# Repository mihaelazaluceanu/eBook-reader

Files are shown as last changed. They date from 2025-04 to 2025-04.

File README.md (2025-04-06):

# eBook Reader - Zaluceanu Mihaela
Dispozitiv electronic, portabil,  folosit drept cititor de e-books, construit în jurul modulului **ESP32-C6-WROOM-1-N8**.

### Diagrama Bloc
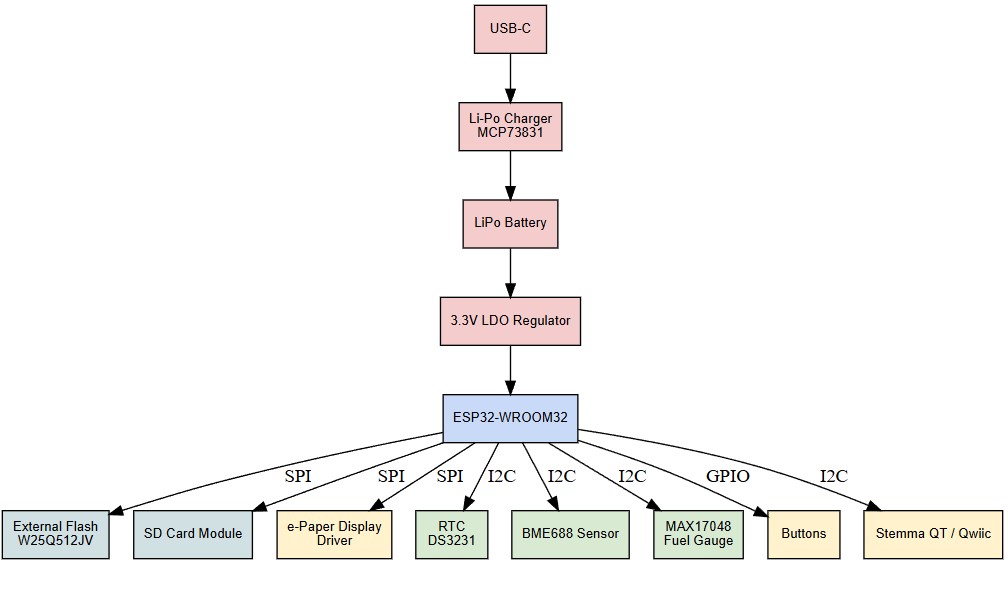
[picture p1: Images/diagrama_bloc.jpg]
Diagrama Bloc


### BOM (Bill of Materials)
**Note:** TP-urile nu apar în tabel deoarece pentru implementarea acestora am folost un design propriu.

  | Nr. | Component Name | Procurement Link | Datasheet Link |
  |-----|----------------|------------------|----------------|
  | 1 | BOOT_BUTON | [Link](https://www.snapeda.com/parts/EVQP7L01P/Panasonic%20Electronic%20Components/view-part/?welcome=home) | [Datasheet](https://www.snapeda.com/parts/EVQP7L01P/Panasonic/datasheet/) |
  | 2 | C1 | [Link](https://componentsearchengine.com/part-view/CC0402MRX5R5BB106/YAGEO) | [Datasheet](https://componentsearchengine.com/Datasheets/2/CC0402MRX5R5BB106.pdf) |
  | 3 | C1_BAT | [Link](https://componentsearchengine.com/part-view/CC0402MRX5R5BB106/YAGEO) | [Datasheet](https://componentsearchengine.com/Datasheets/2/CC0402MRX5R5BB106.pdf) |
  | 4 | C1_BAT2 | [Link](https://componentsearchengine.com/part-view/CC0402MRX5R5BB106/YAGEO) | [Datasheet](https://componentsearchengine.com/Datasheets/2/CC0402MRX5R5BB106.pdf) |
  | 5 | C2 | [Link](https://componentsearchengine.com/part-view/CC0402MRX5R5BB106/YAGEO) | [Datasheet](https://componentsearchengine.com/Datasheets/2/CC0402MRX5R5BB106.pdf) |
  | 6 | C2_BAT | [Link](https://componentsearchengine.com/part-view/CC0402MRX5R5BB106/YAGEO) | [Datasheet](https://componentsearchengine.com/Datasheets/2/CC0402MRX5R5BB106.pdf) |
  | 7 | C3 | [Link](https://componentsearchengine.com/part-view/CC0402MRX5R5BB106/YAGEO) | [Datasheet](https://componentsearchengine.com/Datasheets/2/CC0402MRX5R5BB106.pdf) |
  | 8 | C4 | [Link](https://componentsearchengine.com/part-view/CC0402MRX5R5BB106/YAGEO) | [Datasheet](https://componentsearchengine.com/Datasheets/2/CC0402MRX5R5BB106.pdf) |
  | 9 | C4_USB | [Link](https://componentsearchengine.com/part-view/CC0402MRX5R5BB106/YAGEO) | [Datasheet](https://componentsearchengine.com/Datasheets/2/CC0402MRX5R5BB106.pdf) |
  | 10 | C5 | [Link](https://componentsearchengine.com/part-view/CC0402MRX5R5BB106/YAGEO) | [Datasheet](https://componentsearchengine.com/Datasheets/2/CC0402MRX5R5BB106.pdf) |
  | 11 | C5_USB | [Link](https://componentsearchengine.com/part-view/CC0402MRX5R5BB106/YAGEO) | [Datasheet](https://componentsearchengine.com/Datasheets/2/CC0402MRX5R5BB106.pdf) |
  | 12 | C6 | [Link](https://componentsearchengine.com/part-view/CC0402MRX5R5BB106/YAGEO) | [Datasheet](https://componentsearchengine.com/Datasheets/2/CC0402MRX5R5BB106.pdf) |
  | 13 | C7 | [Link](https://componentsearchengine.com/part-view/CC0402MRX5R5BB106/YAGEO) | [Datasheet](https://componentsearchengine.com/Datasheets/2/CC0402MRX5R5BB106.pdf) |
  | 14 | C8 | [Link](https://componentsearchengine.com/part-view/CC0402MRX5R5BB106/YAGEO) | [Datasheet](https://componentsearchengine.com/Datasheets/2/CC0402MRX5R5BB106.pdf) |
  | 15 | C9 | [Link](https://componentsearchengine.com/part-view/CC0402MRX5R5BB106/YAGEO) | [Datasheet](https://componentsearchengine.com/Datasheets/2/CC0402MRX5R5BB106.pdf) |
  | 16 | C10 | [Link](https://componentsearchengine.com/part-view/CC0402MRX5R5BB106/YAGEO) | [Datasheet](https://componentsearchengine.com/Datasheets/2/CC0402MRX5R5BB106.pdf) |
  | 17 | C10_SUPERCAR | [Link](https://industry.panasonic.com/global/en/products/control/switch/light-touch/number/evqpuj02k) | [Datasheet](https://industry.panasonic.com/global/en/downloads?tab=catalog&small_g_cd=203&part_no=EVQPUJ02K) |
  | 18 | CHANGE_BUTTON | [Link](https://www.snapeda.com/parts/EVQP7L01P/Panasonic%20Electronic%20Components/view-part/?welcome=home) | [Datasheet](https://www.snapeda.com/parts/EVQP7L01P/Panasonic/datasheet/) |
  | 19 | C_DELAY | [Link](https://componentsearchengine.com/part-view/CC0402MRX5R5BB106/YAGEO) | [Datasheet](https://componentsearchengine.com/Datasheets/2/CC0402MRX5R5BB106.pdf) |
  | 20 | D1 | [Link](https://www.snapeda.com/parts/USBLC6-2SC6Y/STMicroelectronics/view-part/?ref=eda) | [Datasheet](https://www.snapeda.com/parts/USBLC6-2SC6Y/STMicroelectronics/view-part/?ref=eda) |
  | 21 | D2 | [Link](https://ro.mouser.com/ProductDetail/KYOCERA-AVX/SD0805S020S1R0?qs=jCA%252BPfw4LHbpkAoSnwrdjw%3D%3D) | [Datasheet](https://ro.mouser.com/datasheet/2/40/schottky-3165252.pdf) |
  | 22 | D3 | [Link](https://ro.mouser.com/ProductDetail/KYOCERA-AVX/SD0805S020S1R0?qs=jCA%252BPfw4LHbpkAoSnwrdjw%3D%3D) | [Datasheet](https://ro.mouser.com/datasheet/2/40/schottky-3165252.pdf) |
  | 23 | D4 | [Link](https://ro.mouser.com/ProductDetail/KYOCERA-AVX/SD0805S020S1R0?qs=jCA%252BPfw4LHbpkAoSnwrdjw%3D%3D) | [Datasheet](https://ro.mouser.com/datasheet/2/40/schottky-3165252.pdf) |
  | 24 | D5 | [Link](https://ro.mouser.com/ProductDetail/KYOCERA-AVX/SD0805S020S1R0?qs=jCA%252BPfw4LHbpkAoSnwrdjw%3D%3D) | [Datasheet](https://ro.mouser.com/datasheet/2/40/schottky-3165252.pdf) |
  | 25 | D6 | [Link](https://www.snapeda.com/parts/PGB1010603MR/Littelfuse/view-part/?ref=eda) | [Datasheet](https://www.snapeda.com/parts/PGB1010603MR/Littelfuse%20Inc./datasheet/) |
  | 26 | D7 | [Link](https://ro.mouser.com/ProductDetail/KYOCERA-AVX/SD0805S020S1R0?qs=jCA%252BPfw4LHbpkAoSnwrdjw%3D%3D) | [Datasheet](https://ro.mouser.com/datasheet/2/40/schottky-3165252.pdf) |
  | 27 | D8 | [Link](https://www.snapeda.com/parts/PGB1010603MR/Littelfuse/view-part/?ref=eda) | [Datasheet](https://www.snapeda.com/parts/PGB1010603MR/Littelfuse%20Inc./datasheet/) |
  | 28 | D9 | [Link](https://www.snapeda.com/parts/PGB1010603MR/Littelfuse/view-part/?ref=eda) | [Datasheet](https://www.snapeda.com/parts/PGB1010603MR/Littelfuse%20Inc./datasheet/) |
  | 29 | D10 | [Link](https://www.snapeda.com/parts/PGB1010603MR/Littelfuse/view-part/?ref=eda) | [Datasheet](https://www.snapeda.com/parts/PGB1010603MR/Littelfuse%20Inc./datasheet/) |
  | 30 | D11 | [Link](https://www.snapeda.com/parts/PGB1010603MR/Littelfuse/view-part/?ref=eda) | [Datasheet](https://www.snapeda.com/parts/PGB1010603MR/Littelfuse%20Inc./datasheet/) |
  | 31 | D12 | [Link](https://www.snapeda.com/parts/PGB1010603MR/Littelfuse/view-part/?ref=eda) | [Datasheet](https://www.snapeda.com/parts/PGB1010603MR/Littelfuse%20Inc./datasheet/) |
  | 32 | EPD_C1 | [Link](https://componentsearchengine.com/part-view/CC0402MRX5R5BB106/YAGEO) | [Datasheet](https://componentsearchengine.com/Datasheets/2/CC0402MRX5R5BB106.pdf) |
  | 33 | EPD_C2 | [Link](https://componentsearchengine.com/part-view/CC0402MRX5R5BB106/YAGEO) | [Datasheet](https://componentsearchengine.com/Datasheets/2/CC0402MRX5R5BB106.pdf) |
  | 34 | EPD_C5 | [Link](https://componentsearchengine.com/part-view/CC0402MRX5R5BB106/YAGEO) | [Datasheet](https://componentsearchengine.com/Datasheets/2/CC0402MRX5R5BB106.pdf) |
  | 35 | EPD_C6 | [Link](https://componentsearchengine.com/part-view/CC0402MRX5R5BB106/YAGEO) | [Datasheet](https://componentsearchengine.com/Datasheets/2/CC0402MRX5R5BB106.pdf) |
  | 36 | EPD_C7 | [Link](https://componentsearchengine.com/part-view/CC0402MRX5R5BB106/YAGEO) | [Datasheet](https://componentsearchengine.com/Datasheets/2/CC0402MRX5R5BB106.pdf) |
  | 37 | EPD_C8 | [Link](https://componentsearchengine.com/part-view/CC0402MRX5R5BB106/YAGEO) | [Datasheet](https://componentsearchengine.com/Datasheets/2/CC0402MRX5R5BB106.pdf) |
  | 38 | EPD_C9 | [Link](https://componentsearchengine.com/part-view/CC0402MRX5R5BB106/YAGEO) | [Datasheet](https://componentsearchengine.com/Datasheets/2/CC0402MRX5R5BB106.pdf) |
  | 39 | EPD_C10 | [Link](https://componentsearchengine.com/part-view/CC0402MRX5R5BB106/YAGEO) | [Datasheet](https://componentsearchengine.com/Datasheets/2/CC0402MRX5R5BB106.pdf) |
  | 40 | EPD_C11 | [Link](https://componentsearchengine.com/part-view/CC0402MRX5R5BB106/YAGEO) | [Datasheet](https://componentsearchengine.com/Datasheets/2/CC0402MRX5R5BB106.pdf) |
  | 41 | EPD_C12 | [Link](https://componentsearchengine.com/part-view/CC0402MRX5R5BB106/YAGEO) | [Datasheet](https://componentsearchengine.com/Datasheets/2/CC0402MRX5R5BB106.pdf) |
  | 42 | IC1 | [Link](https://componentsearchengine.com/part-view/BD5229G-TR/ROHM%20Semiconductor) | [Datasheet](https://datasheet.datasheetarchive.com/originals/distributors/Datasheets_SAMA/f2b9741ef86007909f138d561a359946.pdf) |
  | 43 | IC4 | [Link](https://componentsearchengine.com/part-view/XC6220A331MR-G/Torex) | [Datasheet](https://product.torexsemi.com/system/files/series/xc6220.pdf) |
  | 44 | J1 | [Link](https://componentsearchengine.com/part-view/FH34SRJ-24S-0.5SH(99)/Hirose) | [Datasheet](https://www.hirose.com/en/product/document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) |
  | 45 | J2 | [Link](https://componentsearchengine.com/part-view/USB4110-GF-A/GCT%20(GLOBAL%20CONNECTOR%20TECHNOLOGY)) | [Datasheet](https://gct.co/files/drawings/usb4110.pdf) |
  | 46 | J3 | [Link](https://www.snapeda.com/parts/PRT-14417/SparkFun/view-part/) | [Datasheet](https://www.snapeda.com/parts/PRT-14417/SparkFun%20Electronics/datasheet/) |
  | 47 | J4 | [Link](https://www.snapeda.com/parts/112A-TAAR-R03/Attend/view-part/) | [Datasheet](https://www.snapeda.com/parts/112A-TAAR-R03/Attend/datasheet/) |
  | 48 | MCP73831 | [Link](https://ro.mouser.com/ProductDetail/Microchip-Technology/MCP73831T-2ACI-OT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) | [Datasheet](https://ro.mouser.com/datasheet/2/268/MCP73831_Family_Data_Sheet_DS20001984H-3441711.pdf) |
  | 49 | L1 | [Link](https://ro.mouser.com/ProductDetail/Wurth-Elektronik/744043680?qs=PGXP4M47uW6VkZq%252BkzjrHA%3D%3D) | [Datasheet](https://www.we-online.com/components/products/datasheet/744043680.pdf) |
  | 50 | PFMF.050.1 | [Link](https://ro.mouser.com/ProductDetail/EPCOS-TDK/B72520T0350K062?qs=dEfas%2FXlABIszF52uu7vrg%3D%3D) | [Datasheet](https://www.tdk-electronics.tdk.com/inf/75/db/CTVS_14/Surge_protection_series.pdf) |
  | 51 | Q1 | [Link](https://componentsearchengine.com/part-view/DMG2305UX-7/Diodes%20Incorporated) | [Datasheet](https://www.diodes.com//assets/Datasheets/DMG2305UX.pdf) |
  | 52 | Q2 | [Link](https://componentsearchengine.com/part-view/DMG2305UX-7/Diodes%20Incorporated) | [Datasheet](https://www.diodes.com//assets/Datasheets/DMG2305UX.pdf) |
  | 53 | Q3 | [Link](https://componentsearchengine.com/part-view/SI1308EDL-T1-GE3/Vishay) | [Datasheet](https://componentsearchengine.com/part-view/SI1308EDL-T1-GE3/Vishay) |
  | 54 | R1 | [Link](https://componentsearchengine.com/part-view/R0402%201%25%20100%20K%20(RC0402FR-07100KL)/YAGEO) | [Datasheet](https://www.yageo.com/upload/media/product/products/datasheet/rchip/PYu-RC_Group_51_RoHS_L_12.pdf) |
  | 55 | R1_PINH | [Link](https://componentsearchengine.com/part-view/R0402%201%25%20100%20K%20(RC0402FR-07100KL)/YAGEO) | [Datasheet](https://www.yageo.com/upload/media/product/products/datasheet/rchip/PYu-RC_Group_51_RoHS_L_12.pdf) |
  | 56 | R1_PINH1 | [Link](https://componentsearchengine.com/part-view/R0402%201%25%20100%20K%20(RC0402FR-07100KL)/YAGEO) | [Datasheet](https://www.yageo.com/upload/media/product/products/datasheet/rchip/PYu-RC_Group_51_RoHS_L_12.pdf) |
  | 57 | R1_BAT | [Link](https://componentsearchengine.com/part-view/R0402%201%25%20100%20K%20(RC0402FR-07100KL)/YAGEO) | [Datasheet](https://www.yageo.com/upload/media/product/products/datasheet/rchip/PYu-RC_Group_51_RoHS_L_12.pdf) |
  | 58 | R1_PWRUSB | [Link](https://componentsearchengine.com/part-view/R0402%201%25%20100%20K%20(RC0402FR-07100KL)/YAGEO) | [Datasheet](https://www.yageo.com/upload/media/product/products/datasheet/rchip/PYu-RC_Group_51_RoHS_L_12.pdf) |
  | 59 | R2 | [Link](https://componentsearchengine.com/part-view/R0402%201%25%20100%20K%20(RC0402FR-07100KL)/YAGEO) | [Datasheet](https://www.yageo.com/upload/media/product/products/datasheet/rchip/PYu-RC_Group_51_RoHS_L_12.pdf) |
  | 60 | R2_PINH | [Link](https://componentsearchengine.com/part-view/R0402%201%25%20100%20K%20(RC0402FR-07100KL)/YAGEO) | [Datasheet](https://www.yageo.com/upload/media/product/products/datasheet/rchip/PYu-RC_Group_51_RoHS_L_12.pdf) |
  | 61 | R2-PINH1 | [Link](https://componentsearchengine.com/part-view/R0402%201%25%20100%20K%20(RC0402FR-07100KL)/YAGEO) | [Datasheet](https://www.yageo.com/upload/media/product/products/datasheet/rchip/PYu-RC_Group_51_RoHS_L_12.pdf) |
  | 62 | R2 | [Link](https://componentsearchengine.com/part-view/R0402%201%25%20100%20K%20(RC0402FR-07100KL)/YAGEO) | [Datasheet](https://www.yageo.com/upload/media/product/products/datasheet/rchip/PYu-RC_Group_51_RoHS_L_12.pdf) |
  | 63 | R2-PINH | [Link](https://componentsearchengine.com/part-view/R0402%201%25%20100%20K%20(RC0402FR-07100KL)/YAGEO) | [Datasheet](https://www.yageo.com/upload/media/product/products/datasheet/rchip/PYu-RC_Group_51_RoHS_L_12.pdf) |
  | 64 | R2-PINH1 | [Link](https://componentsearchengine.com/part-view/R0402%201%25%20100%20K%20(RC0402FR-07100KL)/YAGEO) | [Datasheet](https://www.yageo.com/upload/media/product/products/datasheet/rchip/PYu-RC_Group_51_RoHS_L_12.pdf) |
  | 65 | R2_USB | [Link](https://componentsearchengine.com/part-view/R0402%201%25%20100%20K%20(RC0402FR-07100KL)/YAGEO) | [Datasheet](https://www.yageo.com/upload/media/product/products/datasheet/rchip/PYu-RC_Group_51_RoHS_L_12.pdf) |
  | 66 | R2_USB | [Link](https://componentsearchengine.com/part-view/R0402%201%25%20100%20K%20(RC0402FR-07100KL)/YAGEO) | [Datasheet](https://www.yageo.com/upload/media/product/products/datasheet/rchip/PYu-RC_Group_51_RoHS_L_12.pdf) |
  | 67 | R2_USB1 | [Link](https://componentsearchengine.com/part-view/R0402%201%25%20100%20K%20(RC0402FR-07100KL)/YAGEO) | [Datasheet](https://www.yageo.com/upload/media/product/products/datasheet/rchip/PYu-RC_Group_51_RoHS_L_12.pdf) |
  | 68 | R3 | [Link](https://componentsearchengine.com/part-view/R0402%201%25%20100%20K%20(RC0402FR-07100KL)/YAGEO) | [Datasheet](https://www.yageo.com/upload/media/product/products/datasheet/rchip/PYu-RC_Group_51_RoHS_L_12.pdf) |
  | 69 | R4 | [Link](https://componentsearchengine.com/part-view/R0402%201%25%20100%20K%20(RC0402FR-07100KL)/YAGEO) | [Datasheet](https://www.yageo.com/upload/media/product/products/datasheet/rchip/PYu-RC_Group_51_RoHS_L_12.pdf) |
  | 70 | R5 | [Link](https://componentsearchengine.com/part-view/R0402%201%25%20100%20K%20(RC0402FR-07100KL)/YAGEO) | [Datasheet](https://www.yageo.com/upload/media/product/products/datasheet/rchip/PYu-RC_Group_51_RoHS_L_12.pdf) |
  | 71 | R6 | [Link](https://componentsearchengine.com/part-view/R0402%201%25%20100%20K%20(RC0402FR-07100KL)/YAGEO) | [Datasheet](https://www.yageo.com/upload/media/product/products/datasheet/rchip/PYu-RC_Group_51_RoHS_L_12.pdf) |
  | 72 | R7 | [Link](https://componentsearchengine.com/part-view/R0402%201%25%20100%20K%20(RC0402FR-07100KL)/YAGEO) | [Datasheet](https://www.yageo.com/upload/media/product/products/datasheet/rchip/PYu-RC_Group_51_RoHS_L_12.pdf) |
  | 73 | R8 | [Link](https://componentsearchengine.com/part-view/R0402%201%25%20100%20K%20(RC0402FR-07100KL)/YAGEO) | [Datasheet](https://www.yageo.com/upload/media/product/products/datasheet/rchip/PYu-RC_Group_51_RoHS_L_12.pdf) |
  | 74 | R9 | [Link](https://componentsearchengine.com/part-view/R0402%201%25%20100%20K%20(RC0402FR-07100KL)/YAGEO) | [Datasheet](https://www.yageo.com/upload/media/product/products/datasheet/rchip/PYu-RC_Group_51_RoHS_L_12.pdf) |
  | 75 | R10 | [Link](https://componentsearchengine.com/part-view/R0402%201%25%20100%20K%20(RC0402FR-07100KL)/YAGEO) | [Datasheet](https://www.yageo.com/upload/media/product/products/datasheet/rchip/PYu-RC_Group_51_RoHS_L_12.pdf) |
  | 76 | RESET_BUTTON | [Link](https://www.snapeda.com/parts/EVQP7L01P/Panasonic%20Electronic%20Components/view-part/?welcome=home) | [Datasheet](https://www.snapeda.com/parts/EVQP7L01P/Panasonic/datasheet/) |
  | 77 | R_BOOT | [Link](https://componentsearchengine.com/part-view/R0402%201%25%20100%20K%20(RC0402FR-07100KL)/YAGEO) | [Datasheet](https://www.yageo.com/upload/media/product/products/datasheet/rchip/PYu-RC_Group_51_RoHS_L_12.pdf) |
  | 78 | R_CAPACITOR | [Link](https://componentsearchengine.com/part-view/R0402%201%25%20100%20K%20(RC0402FR-07100KL)/YAGEO) | [Datasheet](https://www.yageo.com/upload/media/product/products/datasheet/rchip/PYu-RC_Group_51_RoHS_L_12.pdf) |
  | 79 | R_CHANGE | [Link](https://componentsearchengine.com/part-view/R0402%201%25%20100%20K%20(RC0402FR-07100KL)/YAGEO) | [Datasheet](https://www.yageo.com/upload/media/product/products/datasheet/rchip/PYu-RC_Group_51_RoHS_L_12.pdf) |
  | 80 | R_CL1 | [Link](https://componentsearchengine.com/part-view/R0402%201%25%20100%20K%20(RC0402FR-07100KL)/YAGEO) | [Datasheet](https://www.yageo.com/upload/media/product/products/datasheet/rchip/PYu-RC_Group_51_RoHS_L_12.pdf) |
  | 81 | R_RESET | [Link](https://componentsearchengine.com/part-view/R0402%201%25%20100%20K%20(RC0402FR-07100KL)/YAGEO) | [Datasheet](https://www.yageo.com/upload/media/product/products/datasheet/rchip/PYu-RC_Group_51_RoHS_L_12.pdf) |
  | 82 | SENSOR2 | [Link](https://www.snapeda.com/parts/BME680/Bosch/view-part/?welcome=home) | [Datasheet](https://www.snapeda.com/parts/BME680/Bosch%20Sensortec/datasheet/) |
  | 83 | SJ1 | [Link](https://grabcad.com/library/solder-jumpers-1) | [Datasheet](https://grabcad.com/library/solder-jumpers-1) |
  | 84 | U1 | [Link](https://www.snapeda.com/parts/W25Q512JVEIQ/Winbond+Electronics/view-part/?ref=eda) | [Datasheet](https://www.snapeda.com/parts/W25Q512JVEIQ/Winbond+Electronics/view-part/?ref=eda) |
  | 85 | U2 | [Link](https://www.snapeda.com/parts/ESP32-C6-WROOM-1-N8/Espressif+Systems/view-part/?ref=eda) | [Datasheet](https://www.snapeda.com/parts/ESP32-C6-WROOM-1-N8/Espressif%20Systems/datasheet/) |
  | 86 | U3 | [Link](https://www.snapeda.com/parts/DS3231SN%23/Analog+Devices/view-part/?ref=eda) | [Datasheet](https://www.snapeda.com/parts/DS3231SN%23/Analog%20Devices/datasheet/) |
  | 87 | U4 | [Link](https://www.snapeda.com/parts/MAX17048G+T10/Analog+Devices/view-part/?ref=eda) | [Datasheet](https://www.snapeda.com/parts/MAX17048G+T10/Analog%20Devices/datasheet/) |

### Componente principale ale sistemului:

- **ESP32-C6-WROOM-1-N8** – Microcontroler principal cu conectivitate Wi-Fi și Bluetooth Low Energy (BLE) integrată. Responsabil pentru gestionarea comunicațiilor, a senzorilor și a afișajului.
- **BME688** – Senzor de mediu capabil să măsoare temperatura, umiditatea, presiunea atmosferică și compuși volatili (calitatea aerului). Comunică cu ESP32 prin interfața **I2C**.
- **DS3231SN** – Modul RTC (ceas în timp real) de înaltă precizie, conectat la ESP32 tot prin magistrala **I2C**, asigură păstrarea timpului chiar și în lipsa alimentării.
- **MAX17048** – Circuit de monitorizare a nivelului bateriei cu interfață **I2C**; oferă informații despre starea de încărcare (SOC - State of Charge).
- **Modul card SD** – Utilizat pentru stocarea locală a datelor colectate. Comunică prin interfața **SPI**.
- **Display E-Ink** – Afișaj monocrom cu consum foarte redus de energie, controlat prin **SPI**. Semnale de control: `EPD_CS`, `EPD_DC`, `EPD_RST`, `EPD_BUSY`;
- **Memorie NOR Flash (W25Q512JVEIQ, 64MB)** – Memorie externă conectată prin **SPI**, destinată stocării de firmware sau volume mari de date;
- **Butoane BOOT și RESET** – Conectate la pini GPIO ai ESP32, permit intrarea în modul bootloader și resetarea sistemului;
- **MCP73831** – Controler de încărcare pentru acumulatori Li-Po, conectat direct la baterie pentru gestionarea încărcării în siguranță;
- **LDO (Low Dropout Regulator) XC6220A331MR-G** – Regulator de tensiune de 3.3V, furnizează alimentarea stabilă pentru componentele logice;
- **Port USB-C (USB4110-GF-A)** – Asigură alimentarea dispozitivului, precum și comunicația serială pentru programare și depanare.

### ESP32-C6 Pin Mapping

| Pin ESP32-C6 | Componentă Legată | Funcție |
|---|---|---|
| GPIO0 | Flash Memory (DI) | SPI MOSI |
| GPIO1 | Flash Memory (DO) | SPI MISO |
| GPIO2 | Flash CS | Chip Select |
| GPIO3 | Flash HOLD | Hold/Reset |
| GPIO6 | E-Ink Display (EPD_DC)  | Data/Command Select  |
| GPIO7 | E-Ink Display (EPD_CS)  | Chip Select |
| GPIO8 | E-Ink Display (EPD_RST) | Reset |
| GPIO9 | E-Ink Display (BUSY) | Status Feedback |
| GPIO10 | SD Card (CS) | Chip Select |
| GPIO11 | SD Card (MOSI) | Data In |
| GPIO12 | SD Card (MISO) | Data Out |
| GPIO13 | SD Card (CLK) | Clock |
| GPIO16/17 | UART | Serial TX / RX |
| GPIO18/19 | I2C | SDA / SCL |
| GPIO20 | MAX17048 Alert | Battery Warning |

### Alte Detalii Relevante

- **Vizualizări 3D**: Disponibile în directorul `Images/` și în secțiunea `Mechanical/`;
- **Proiectul carcasei și modelarea 3D**: Conține modelul integral realizat în Fusion360 și fișierul exportat în format `.step`, localizat în `Mechanical/`.
- **Organizarea componentelor**: Corespunde cu specificațiile din cerință, inclusiv potrivirea cu elementele carcasei;
- **Test pad-uri**: Etichetate clar în stratul de inscripționare, implementate pentru semnalele importante (MOSI, MISO, Rx, etc.).

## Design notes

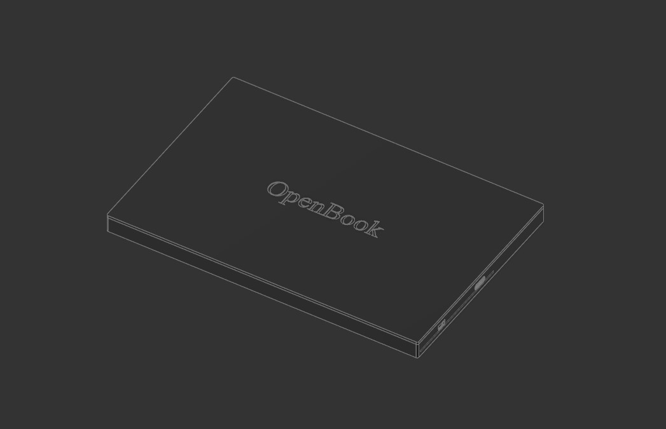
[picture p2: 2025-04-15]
Final Prod/Imgs/disp_asambl_back.jpg

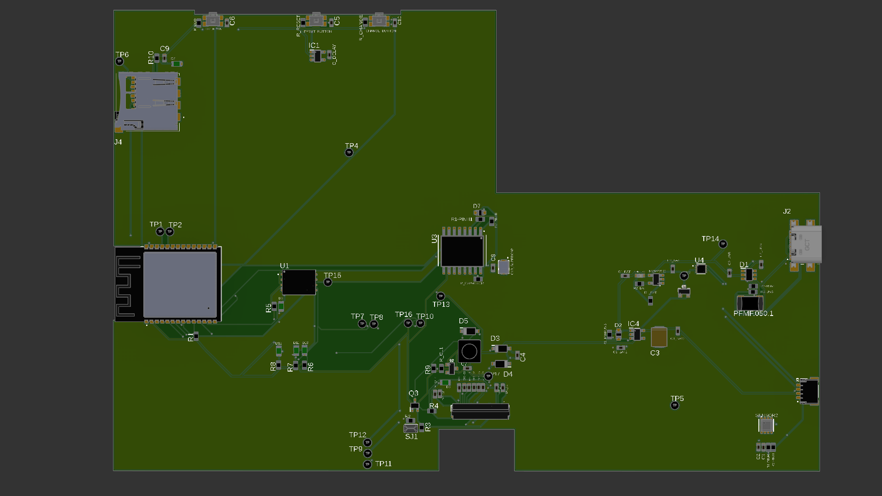
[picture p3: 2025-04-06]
Images/3D Board Front.png

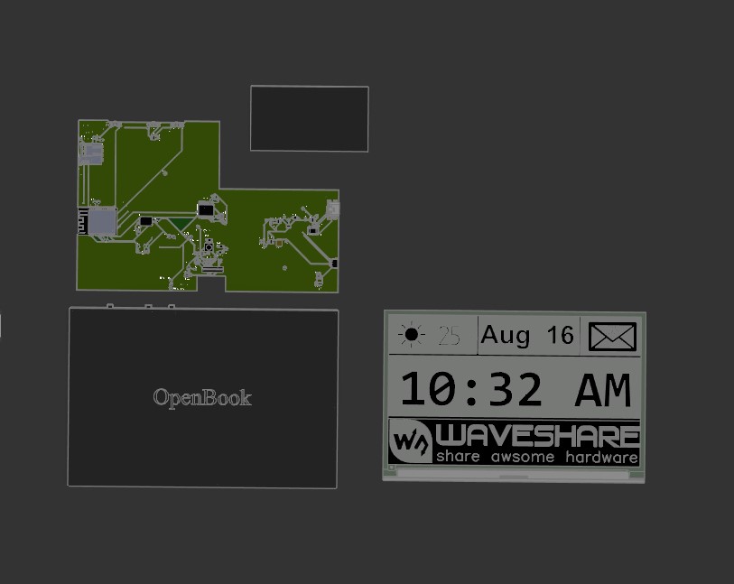
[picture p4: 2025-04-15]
Final Prod/Imgs/disp_dezasm.jpg

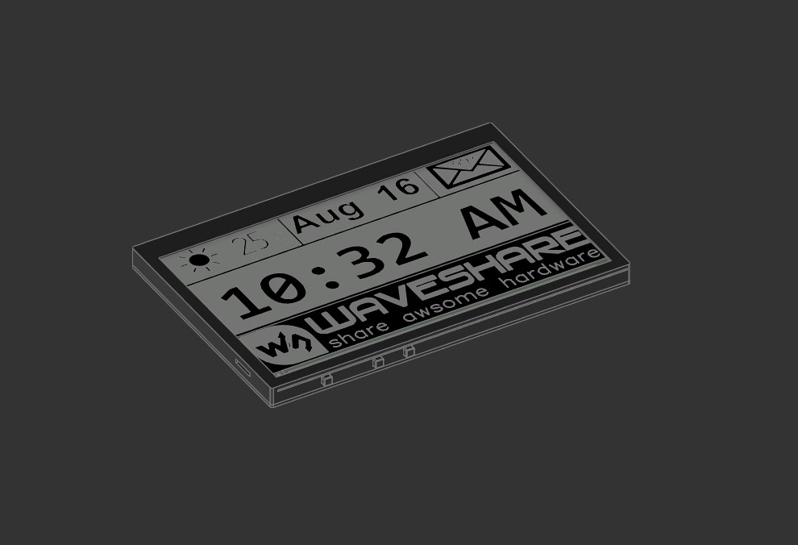
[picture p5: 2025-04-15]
Final Prod/Imgs/disp_asambl_front.jpg

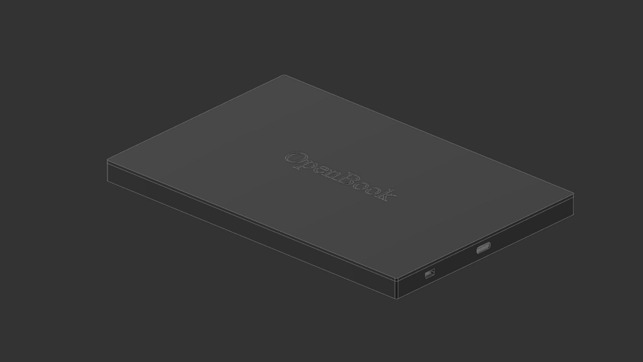
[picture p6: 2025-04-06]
Images/Dispozitiv Final Back.jpg

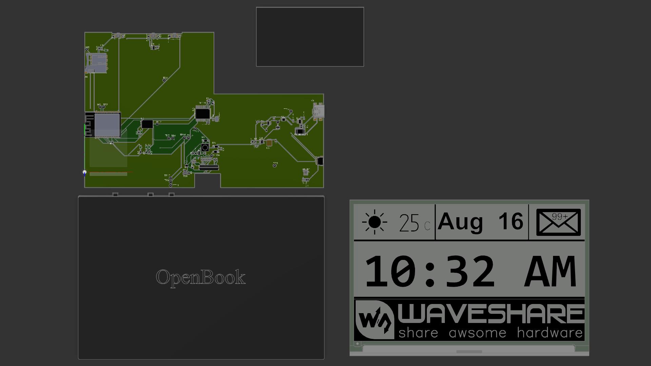
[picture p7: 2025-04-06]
Images/Dispozitiv Img.jpg

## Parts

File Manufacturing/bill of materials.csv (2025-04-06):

Qty | Value | Device | Package | Parts | Description | ARROW_PART_NUMBER | ARROW_PRICE-STOCK | AVAILABILITY | CENTROID_NOT_SPECIFIED | CHECK_PRICES | COPYRIGHT | DATASHEET | DESCRIPTION | DIGIKEY_DESCRIPTION | DIGIKEY_PART_NUMBER | HEIGHT | LEAD_FREE | MANUFACTURER_NAME | MANUFACTURER_PART_NUMBER | MF | MFR_NAME | MOUSER_PART_NUMBER | MOUSER_PRICE-STOCK | MOUSER_TESTING_PART_NUMBER | MOUSER_TESTING_PRICE-STOCK | MP | MPN | PACKAGE | POPULARITY | PREFIX | PRICE | PROD_ID | PURCHASE-URL | ROHS | SNAPEDA_LINK | SPICEMODEL | SPICEPREFIX | TEMPERATURE_RANGE_HIGH | TEMPERATURE_RANGE_LOW | TP_SIGNAL_NAME | VALUE
1 |  | ADAFRUIT_LEDCHIP-LED0603 | ADAFRUIT_CHIP-LED0603 | CHG_LED | LED
1 |  | ESP32C6_VARISTORCN1812 | ESP32C6_VARISTOR_CT/CN1812 | PFMF.050.1 | VARISTOR |  |  |  |  |  |  |  |  |  |  |  |  |  |  |  |  |  |  |  |  |  |  |  | 0
1 |  | SAMACSYS_PARTS_USB4110-GF-A | SAMACSYS_PARTS_USB4110GFA | J2 | CONN USB 2.0 TYPE-C R/A SMT |  |  |  |  |  |  |  | CONN USB 2.0 TYPE-C R/A SMT |  |  | 3.26mm |  | GCT (GLOBAL CONNECTOR TECHNOLOGY) | USB4110-GF-A |  |  | 640-USB4110-GF-A | https://www.mouser.co.uk/ProductDetail/GCT/USB4110-GF-A?qs=KUoIvG%2F9IlYiZvIXQjyJeA%3D%3D
1 |  | SJ | SJ | SJ1 | SMD solder JUMPER |  |  |  |  |  |  |  |  |  |  |  |  |  |  |  |  |  |  |  |  |  |  |  | 3
1 | 0.1uF/50V | ESP32_WROVER_EAGLE-LTSPICE_CC0402 | EAGLE-LTSPICE_C0402 | EPD_C5 | CAPACITOR, European symbol |  |  |  |  |  |  |  |  |  |  |  |  |  |  |  |  |  |  |  |  |  |  |  |  |  |  |  |  |  |  | NONE | C
1 | 0.47 | ESP32_WROVER_EAGLE-LTSPICE_RR0402 | ESP32_WROVER_EAGLE-LTSPICE_R0402 | R3 | RESISTOR, European symbol |  |  |  |  |  |  |  |  |  |  |  |  |  |  |  |  |  |  |  |  |  |  |  |  |  |  |  |  |  |  | NONE | R
1 | 100K | ESP32_WROVER_EAGLE-LTSPICE_RR0402 | ESP32_WROVER_EAGLE-LTSPICE_R0402 | R1_PWRUSB | RESISTOR, European symbol |  |  |  |  |  |  |  |  |  |  |  |  |  |  |  |  |  |  |  |  |  |  |  |  |  |  |  |  |  |  |  | R
2 | 100nF | EAGLE-LTSPICE_CC0402 | EAGLE-LTSPICE_C0402 | C4_USB, C9 | CAPACITOR, European symbol |  |  |  |  |  |  |  |  |  |  |  |  |  |  |  |  |  |  |  |  |  |  |  |  |  |  |  |  |  |  | NONE | C
6 | 100nF | ESP32_WROVER_EAGLE-LTSPICE_CC0402 | EAGLE-LTSPICE_C0402 | C1, C2, C6, C8, C10, C_DELAY | CAPACITOR, European symbol |  |  |  |  |  |  |  |  |  |  |  |  |  |  |  |  |  |  |  |  |  |  |  |  |  |  |  |  |  |  | NONE | C
1 | 100uF TANT | RCL_CPOL-EUCT3528 | RCL_CT3528 | C3 | POLARIZED CAPACITOR, European symbol |  |  |  |  |  |  |  |  |  |  |  |  |  |  |  |  |  |  |  |  |  |  |  | 0 |  |  |  |  |  |  |  | C
15 | 10K | ESP32_WROVER_EAGLE-LTSPICE_RR0402 | ESP32_WROVER_EAGLE-LTSPICE_R0402 | R1, R1-PINH, R1-PINH1, R2-PINH, R2-PINH1, R5, R6, R7, R8, R9, R10, R_BOOT, R_CHANGE, R_CL1, R_RESET | RESISTOR, European symbol |  |  |  |  |  |  |  |  |  |  |  |  |  |  |  |  |  |  |  |  |  |  |  |  |  |  |  |  |  |  | NONE | R
1 | 10k | ESP32_WROVER_EAGLE-LTSPICE_RR0402 | ESP32_WROVER_EAGLE-LTSPICE_R0402 | R4 | RESISTOR, European symbol |  |  |  |  |  |  |  |  |  |  |  |  |  |  |  |  |  |  |  |  |  |  |  |  |  |  |  |  |  |  | NONE | R
1 | 10uF | ESP32_WROVER_EAGLE-LTSPICE_CC0402 | EAGLE-LTSPICE_C0402 | C7 | CAPACITOR, European symbol |  |  |  |  |  |  |  |  |  |  |  |  |  |  |  |  |  |  |  |  |  |  |  |  |  |  |  |  |  |  | NONE | C
1 | 112A-TAAR-R03_ATTEND | 112A-TAAR-R03_ATTEND | 112ATAARR03ATTEND | J4 | Micro SD Card Socket, Push-Push Type, Top Mount, SMT, H=1.83mm, 10u |  |  |  |  |  |  |  | Micro SD Card Socket | Push-Push Type | Top Mount | SMT | H=1.83mm | 10u |  |  | 1.9mm |  | ATTEND | 112A-TAAR-R03 ATTEND
1 | 15 | ESP32_WROVER_EAGLE-LTSPICE_RR0402 | ESP32_WROVER_EAGLE-LTSPICE_R0402 | R_CAPACITOR | RESISTOR, European symbol |  |  |  |  |  |  |  |  |  |  |  |  |  |  |  |  |  |  |  |  |  |  |  |  |  |  |  |  |  |  | NONE | R
1 | 1uF | ESP32_WROVER_EAGLE-LTSPICE_CC0402 | EAGLE-LTSPICE_C0402 | C5 | CAPACITOR, European symbol |  |  |  |  |  |  |  |  |  |  |  |  |  |  |  |  |  |  |  |  |  |  |  |  |  |  |  |  |  |  | NONE | C
9 | 1uF/50V | ESP32_WROVER_EAGLE-LTSPICE_CC0402 | EAGLE-LTSPICE_C0402 | EPD_C1, EPD_C2, EPD_C6, EPD_C7, EPD_C8, EPD_C9, EPD_C10, EPD_C11, EPD_C12 | CAPACITOR, European symbol |  |  |  |  |  |  |  |  |  |  |  |  |  |  |  |  |  |  |  |  |  |  |  |  |  |  |  |  |  |  | NONE | C
1 | 2.2 | ESP32_WROVER_EAGLE-LTSPICE_RR0402 | ESP32_WROVER_EAGLE-LTSPICE_R0402 | R2 | RESISTOR, European symbol |  |  |  |  |  |  |  |  |  |  |  |  |  |  |  |  |  |  |  |  |  |  |  |  |  |  |  |  |  |  | NONE | R
1 | 200 | ESP32_WROVER_EAGLE-LTSPICE_RR0402 | ESP32_WROVER_EAGLE-LTSPICE_R0402 | R1_BAT | RESISTOR, European symbol |  |  |  |  |  |  |  |  |  |  |  |  |  |  |  |  |  |  |  |  |  |  |  |  |  |  |  |  |  |  | NONE | R
2 | 20V/4.2A/52mO/1.4W | ESP32_WROVER_SPARKFUN-DISCRETESEMI_MOSFET_PCH-DMG2305UX-7 | ESP32_WROVER_SPARKFUN-DISCRETESEMI_SOT23-3 | Q1, Q2 | P-channel MOSFETs |  |  |  |  |  |  |  |  |  |  |  |  |  |  |  |  |  |  |  |  |  |  |  |  |  |  | TRAN-14388 |  |  |  |  |  |  |  |  | 20V/4.2A/52mO/1.4W
1 | 2K | ESP32_WROVER_EAGLE-LTSPICE_RR0402 | ESP32_WROVER_EAGLE-LTSPICE_R0402 | R2_BAT | RESISTOR, European symbol |  |  |  |  |  |  |  |  |  |  |  |  |  |  |  |  |  |  |  |  |  |  |  |  |  |  |  |  |  |  | NONE | R
3 | 4.7uF | EAGLE-LTSPICE_CC0402 | EAGLE-LTSPICE_C0402 | C5_USB, C1_BAT1, C1_BAT2 | CAPACITOR, European symbol |  |  |  |  |  |  |  |  |  |  |  |  |  |  |  |  |  |  |  |  |  |  |  |  |  |  |  |  |  |  | NONE | C
2 | 4.7uF | ESP32_WROVER_EAGLE-LTSPICE_CC0402 | EAGLE-LTSPICE_C0402 | C1_BAT, C2_BAT | CAPACITOR, European symbol |  |  |  |  |  |  |  |  |  |  |  |  |  |  |  |  |  |  |  |  |  |  |  |  |  |  |  |  |  |  | NONE | C
1 | 4.7uF/25V | ESP32_WROVER_EAGLE-LTSPICE_CC0402 | EAGLE-LTSPICE_C0402 | C4 | CAPACITOR, European symbol |  |  |  |  |  |  |  |  |  |  |  |  |  |  |  |  |  |  |  |  |  |  |  |  |  |  |  |  |  |  | NONE | C
2 | 5k1 | ESP32_WROVER_EAGLE-LTSPICE_RR0402 | ESP32_WROVER_EAGLE-LTSPICE_R0402 | R2-USB, R2-USB1 | RESISTOR, European symbol |  |  |  |  |  |  |  |  |  |  |  |  |  |  |  |  |  |  |  |  |  |  |  |  |  |  |  |  |  |  | NONE | R
1 | 68uH | 744043680IND_4828-WE-TPC_WRE | IND_4828-WE-TPC_WRE | L1 |  |  |  |  |  |  | Copyright (C) 2024 Ultra Librarian. All rights reserved. |  |  |  |  |  |  |  | 744043680 |  | Wurth Electronics
1 | BD5229G-TR | BD5229G-TR | SOT95P280X125-5N | IC1 | Voltage Detector with Adjustable Delay Time: CMOS processes are utilized to develop high precision, low current consumption CMOS reset ICs that allow arbitrary setting of the delay time. The extensive lineup includes both Nch Open Drain and CMOS output types in a wide range of detection voltages (from 2.3V to 6.0V, in 0.1V steps), enabling selection of the ideal solution based on customer requirements. In addition, the entire series is of course both lead-free and RoHS-compliant. |  |  |  |  |  |  |  | Voltage Detector with Adjustable Delay Time: CMOS processes are utilized to develop high precision | low current consumption CMOS reset ICs that allow arbitrary setting of the delay time. The extensive lineup includes both Nch Open Drain and CMOS output types in a wide range of detection voltages (from 2.3V to 6.0V | in 0.1V steps) | enabling selection of the ideal solution based on customer requirements. In addition | the entire series is of course both lead-free and RoHS-compliant. |  |  | 1.25mm |  | ROHM Semiconductor | BD5229G-TR |  |  | 755-BD5229G-TR | https://www.mouser.co.uk/ProductDetail/ROHM-Semiconductor/BD5229G-TR?qs=4kLU8WoGk0vvnhrrYwdszw%3D%3D
3 | BUTTON_CUSYOMV1 | BUTTON_CUSYOMV1 | MYBUTTON | BOOT_BUTTON, CHANGE_BUTTON, RESET_BUTTON
1 | CPH3225A | CPH3225A | CAPCP3225X100N | C10_SUPERCAP | Cap 0.011F 3.3V 1210 Flat Check availability |  |  | Not in stock |  | https://www.snapeda.com/parts/CPH3225A/Seiko+Instruments/view-part/?ref=eda |  |  | 11 mF (EDLC) Supercapacitor 3.3 V 1210 (3225 Metric) - - |  |  |  |  |  |  | Seiko Instruments |  |  |  |  |  | CPH3225A |  | 1210 Seiko |  |  | None |  | https://www.snapeda.com/api/url_track_click_mouser/?unipart_id=562593&manufacturer=Seiko Instruments&part_name=CPH3225A&search_term=None |  | https://www.snapeda.com/parts/CPH3225A/Seiko+Instruments/view-part/?ref=snap
1 | DS3231SN# | DS3231SN# | SOIC127P1032X265-16N | U3 | Real Time Clock Serial 16-Pin SOIC W T/R Check availability |  |  | In Stock |  | https://www.snapeda.com/parts/DS3231SN%23/Analog+Devices/view-part/?ref=eda |  |  | Extremely Accurate I²C-Integrated RTC/TCXO/Crystal |  |  |  |  |  |  | Analog Devices |  |  |  |  |  | DS3231SN# |  | SOIC-16 Maxim |  |  | None |  | https://www.snapeda.com/api/url_track_click_mouser/?unipart_id=99048&manufacturer=Analog Devices&part_name=DS3231SN#&search_term=None |  | https://www.snapeda.com/parts/DS3231SN%23/Analog+Devices/view-part/?ref=snap
1 | ESP32-C6-WROOM-1-N8 | ESP32-C6-WROOM-1-N8 | XCVR_ESP32-C6-WROOM-1-N8 | U2 | Check availability |  |  | In Stock |  | https://www.snapeda.com/parts/ESP32-C6-WROOM-1-N8/Espressif+Systems/view-part/?ref=eda |  |  | Multiprotocol Modules ESP32-C6 module | Wi-Fi 6 in 2.4 GHz band | Bluetooth 5 | Zigbee 3.0 and Thread. ESP34-WROOM Compatible - ENGINEERING SAMPLE |  |  |  |  |  |  | Espressif Systems |  |  |  |  |  | ESP32-C6-WROOM-1-N8 |  | None |  |  | None |  |  |  | https://www.snapeda.com/parts/ESP32-C6-WROOM-1-N8/Espressif+Systems/view-part/?ref=snap
2 | ESP32_WROVER_AVX---SD0805S020S1R0_AVX_SD0805S020S1R0_0_0AVX_SD0805S020S1R0_0_0 | ESP32_WROVER_AVX---SD0805S020S1R0_AVX_SD0805S020S1R0_0_0AVX_SD0805S020S1R0_0_0 | ESP32_WROVER_AVX---SD0805S020S1R0_AVX_SD0805S020S1R0_0 | D2, D7 | Schottky Barrier Rectifier Diode |  |  |  | No |  |  | http://datasheets.avx.com/schottky.pdf |  | DIODE SCHOTTKY 20V 1A 0805 | 478-7800-1-ND |  | yes |  |  | AVX |  | 581-SD0805S020S1R0 |  |  |  |  |  | 0805 (2012 metric) |  | D |  |  |  | yes |  |  |  | +125°C | -55°C
1 | ESP32_WROVER_BME680_BME680 | ESP32_WROVER_BME680_BME680 | ESP32_WROVER_BME680_PSON80P300X300X100-8N | SENSOR2 | Integrated Environmental Unit |  |  | Unavailable |  |  |  |  | Integrated Environmental Unit |  |  |  |  |  |  | Bosch Sensortec |  |  |  |  |  | BME680 |  | LGA-8 Bosch Tools |  |  | None
1 | ESP32_WROVER_SPARKFUN-IC-POWER_MCP73831 | ESP32_WROVER_SPARKFUN-IC-POWER_MCP73831 | ESP32_WROVER_SPARKFUN-IC-POWER_SOT23-5 | MCP73831 | MCP73831T Li-Ion, Li-Pol Controller |  |  |  |  |  |  |  |  |  |  |  |  |  |  |  |  |  |  |  |  |  |  |  |  |  |  | IC-09995
1 | FH34SRJ-24S-0.5SH_99_ | FH34SRJ-24S-0.5SH_99_ | FH34SRJ24S05SH99 | J1 | (0.50mm) Surface Mount, Right Angle |  |  |  |  |  |  |  | 24 Position FFC | FPC Connector Contacts | (0.50mm) Surface Mount | Right Angle |  |  | 1.1mm |  | Hirose | FH34SRJ-24S-0.5SH(99) |  |  | 798-FH34SRJ24S05SH99 | https://www.mouser.co.uk/ProductDetail/Hirose-Connector/FH34SRJ-24S-0.5SH99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
1 | MAX17048G+T10 | MAX17048G+T10 | SON50P200X200X80-9N | U4 | Check availability |  |  | In Stock |  | https://www.snapeda.com/parts/MAX17048G+T10/Analog+Devices/view-part/?ref=eda |  |  | 3µA 1-Cell/2-Cell Fuel Gauge with ModelGauge |  |  |  |  |  |  | Analog Devices |  |  |  |  |  | MAX17048G+T10 |  | TDFN-8 Maxim |  |  | None |  | https://www.snapeda.com/api/url_track_click_mouser/?unipart_id=329239&manufacturer=Analog Devices&part_name=MAX17048G+T10&search_term=None |  | https://www.snapeda.com/parts/MAX17048G+T10/Analog+Devices/view-part/?ref=snap
3 | MBR0530 | MBR0530 | SOD3716X135N | D3, D4, D5 | ON SEMICONDUCTOR - MBR0530 - DIODE, SCHOTTKY, 0.5A, 30V, SOD-123 |  |  | In Stock |  | https://www.snapeda.com/parts/MBR0530/Onsemi/view-part/?ref=eda |  |  | Diode Schottky 30 V 500mA Surface Mount SOD-123 |  |  |  |  |  |  | ON Semiconductor |  |  |  |  |  | MBR0530 |  | SOD-123-2 ON Semiconductor |  |  | None |  | https://www.snapeda.com/api/url_track_click_mouser/?unipart_id=179458&manufacturer=ON Semiconductor&part_name=MBR0530&search_term=None |  | https://www.snapeda.com/parts/MBR0530/Onsemi/view-part/?ref=snap
6 | PGB1010603MR | PGB1010603MR | DIOC1608X36N | D6, D8, D9, D10, D11, D12 | Check availability |  |  | In Stock |  | https://www.snapeda.com/parts/PGB1010603MR/Littelfuse/view-part/?ref=eda |  |  | 150V (Typ) Clamp - Ipp Tvs Diode Surface Mount 0603 (1608 Metric) |  |  |  |  |  |  | Littelfuse Inc. |  |  |  |  |  | PGB1010603MR |  | 0603 Littelfuse Inc. |  |  | None |  | https://www.snapeda.com/api/url_track_click_mouser/?unipart_id=5659453&manufacturer=Littelfuse Inc.&part_name=PGB1010603MR&search_term=None |  | https://www.snapeda.com/parts/PGB1010603MR/Littelfuse/view-part/?ref=snap
1 | QWIIC_RIGHT_ANGLE | QWIIC_CONNECTORJS-1MM | JST04_1MM_RA | J3 | SparkFun I2C Standard Qwiic Connector |  |  |  |  |  |  |  |  |  |  |  |  |  |  |  |  |  |  |  |  |  |  |  |  |  |  | CONN-13694 |  |  |  |  |  |  |  |  | QWIIC_RIGHT_ANGLE
1 | SI1308EDL-T1-GE3 | SI1308EDL-T1-GE3 | SOT65P210X110-3N | Q3 | MOSFET N-Ch 30V 1.5A TrenchFET SC70 Vishay Si1308EDL-T1-GE3 N-channel MOSFET Transistor, 1.5 A, 30 V, 3-Pin SC-70 |  |  | In Stock |  | https://www.snapeda.com/parts/SI1308EDL-T1-GE3/Vishay+Siliconix/view-part/?ref=eda |  |  | Si1308EDL-T1-GE3 N-channel MOSFET Transistor | 1.5 A | 30 V | 3-Pin SC-70 | Siliconix / Vishay SI1308EDL-T1-GE3 |  |  |  |  |  |  | Vishay Siliconix |  |  |  |  |  | SI1308EDL-T1-GE3 |  | SOT-323 Vishay Semiconductor |  |  | None |  | https://www.snapeda.com/api/url_track_click_mouser/?unipart_id=274603&manufacturer=Vishay Siliconix&part_name=SI1308EDL-T1-GE3&search_term=None |  | https://www.snapeda.com/parts/SI1308EDL-T1-GE3/Vishay+Siliconix/view-part/?ref=snap
17 | TPTP20R | TPTP20R | TP20R | TP1, TP2, TP3, TP4, TP5, TP6, TP7, TP8, TP9, TP10, TP11, TP12, TP13, TP14, TP15, TP16, TP17 | Test pad |  |  |  |  |  |  |  |  |  |  |  |  |  |  |  |  |  |  |  |  |  |  |  | 2
1 | USBLC6-2SC6Y | USBLC6-2SC6Y | SOT95P280X145-6N | D1 | Low Cap. ESD Protection Auto SOT-23-6 STMicroelectronics USBLC6-2SC6Y, Dual Uni-Directional TVS Diode Array, 6-Pin SOT-23 |  |  | In Stock |  | https://www.snapeda.com/parts/USBLC6-2SC6Y/STMicroelectronics/view-part/?ref=eda |  |  | 17V Clamp 5A (8/20µs) Ipp Tvs Diode Surface Mount SOT-23-6 |  |  |  |  |  |  | STMicroelectronics |  |  |  |  |  | USBLC6-2SC6Y |  | SOT-23-6 STMicroelectronics |  |  | None |  |  |  | https://www.snapeda.com/parts/USBLC6-2SC6Y/STMicroelectronics/view-part/?ref=snap
1 | W25Q512JVEIQ | W25Q512JVEIQ | SON127P600X800X80-9N | U1 | Check availability |  |  | In Stock |  | https://www.snapeda.com/parts/W25Q512JVEIQ/Winbond+Electronics/view-part/?ref=eda |  |  | FLASH - NOR Memory IC 512Mb (64M x 8) SPI - Quad I/O 133 MHz 8-WSON (8x6) |  |  |  |  |  |  | Winbond Electronics |  |  |  |  |  | W25Q512JVEIQ |  | Package |  |  | None |  |  |  | https://www.snapeda.com/parts/W25Q512JVEIQ/Winbond+Electronics/view-part/?ref=snap
1 | XC6220A331MR-G | XC6220A331MR-G | SOT95P280X120-5N | IC4 | LDO Voltage Regulators |  |  |  |  |  |  |  | LDO Voltage Regulators |  |  | 1.2mm |  | Torex | XC6220A331MR-G |  |  | 865-XC6220A331MR-G | https://www.mouser.co.uk/ProductDetail/Torex-Semiconductor/XC6220A331MR-G?qs=AsjdqWjXhJ8ZSWznL1J0gg%3D%3D

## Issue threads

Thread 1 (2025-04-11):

Diferențe față de schematicul dat

ralucaguceanu, 2025-04-11:
Când am comparat schematicul propus cu cel din proiect, am observat următoarele diferențe:
- la piesa Q1 lipsește un fir
- la butoane unii pini nu sunt conectați
- condensatorul C10SUPERCAP este poziționat invers

Closed 2025-04-15.

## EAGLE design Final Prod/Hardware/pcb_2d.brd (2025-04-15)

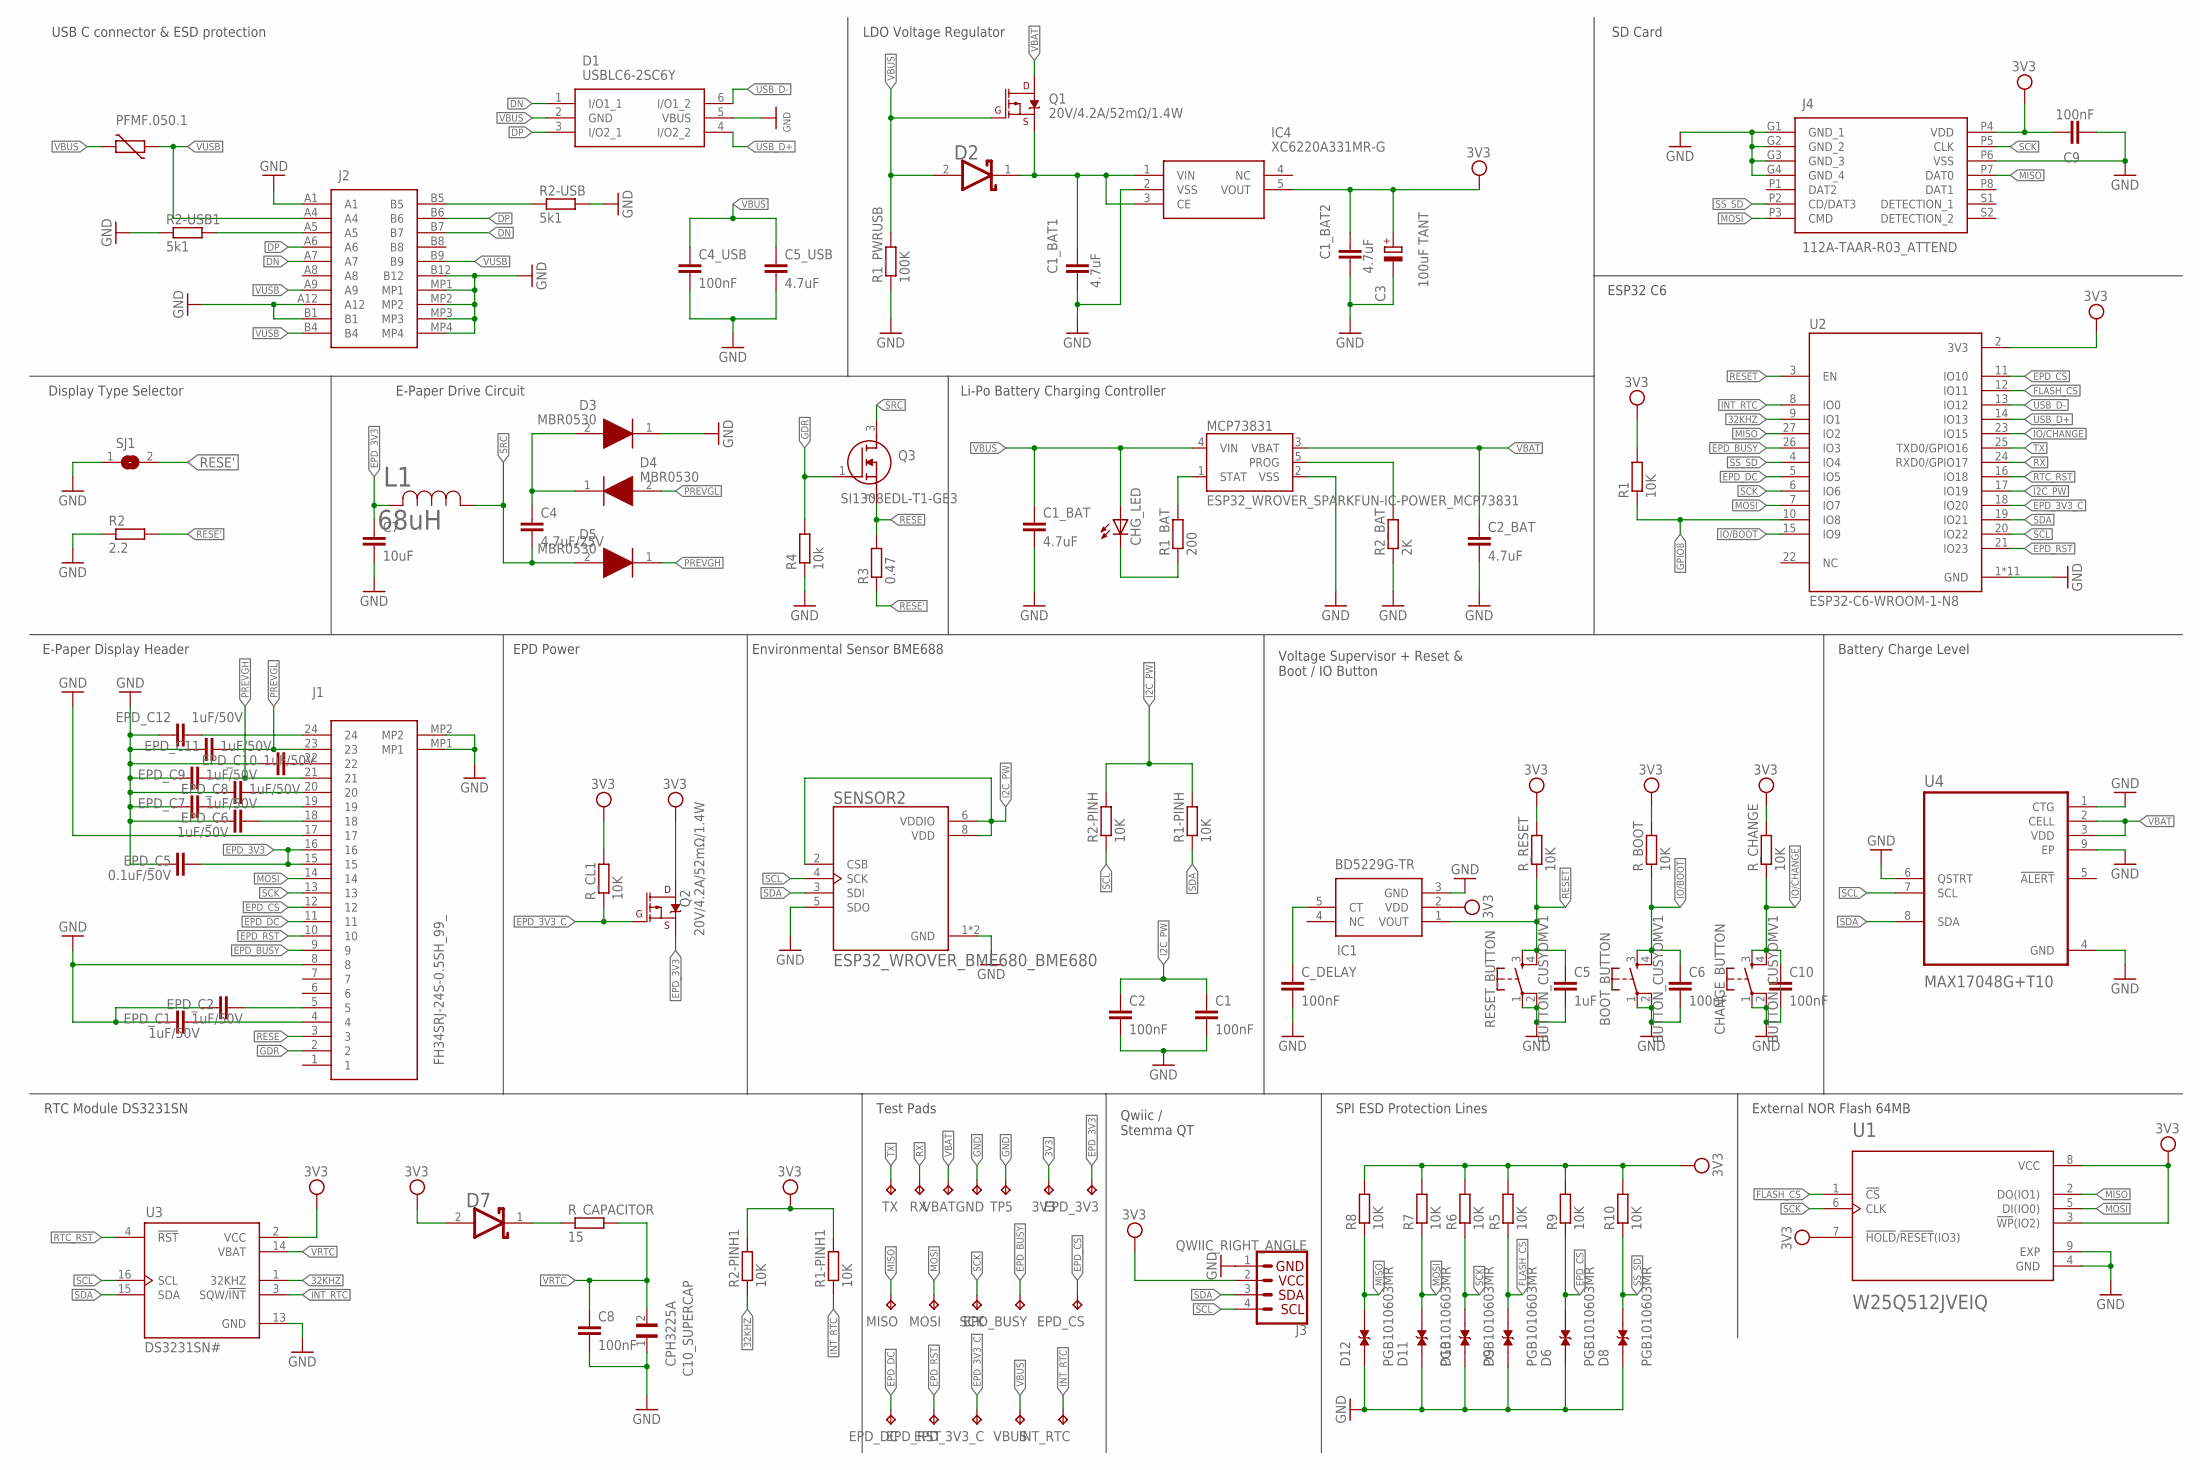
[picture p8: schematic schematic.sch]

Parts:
3V3: TPTP20R; TP20R
BOOT_BUTTON: BUTTON_CUSYOMV1; MYBUTTON
C1, C2, C6, C8, C10: 100nF; EAGLE-LTSPICE_C0402
C1_BAT, C2_BAT: 4.7uF; EAGLE-LTSPICE_C0402
C1_BAT1, C1_BAT2, C5_USB: 4.7uF; ESP32_WROVER_EAGLE-LTSPICE_C0402
C3: 100uF TANT; RCL_CT3528
C4: 4.7uF/25V; EAGLE-LTSPICE_C0402
C4_USB, C9: 100nF; ESP32_WROVER_EAGLE-LTSPICE_C0402
C5: 1uF; EAGLE-LTSPICE_C0402
C7: 10uF; EAGLE-LTSPICE_C0402
C10_SUPERCAP: CPH3225A; CAPCP3225X100N
CHANGE_BUTTON: BUTTON_CUSYOMV1; MYBUTTON
CHG_LED: ADAFRUIT_LEDCHIP-LED0603; ADAFRUIT_CHIP-LED0603
C_DELAY: 100nF; EAGLE-LTSPICE_C0402
D1: USBLC6-2SC6Y; SOT95P280X145-6N
D2, D7: ESP32_WROVER_AVX---SD0805S020S1R0_AVX_SD0805S020S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; ESP32_WROVER_AVX---SD0805S020S1R0_AVX_SD0805S020S1R0_0
D3, D4, D5: MBR0530; SOD3716X135N
D6, D8, D9, D10, D11, D12: PGB1010603MR; DIOC1608X36N
EPD_3V3, EPD_3V3_C: TPTP20R; TP20R
EPD_BUSY: TPTP20R; TP20R
EPD_C1, EPD_C2, EPD_C6, EPD_C7, EPD_C8, EPD_C9, EPD_C10, EPD_C11, EPD_C12: 1uF/50V; EAGLE-LTSPICE_C0402
EPD_C5: 0.1uF/50V; EAGLE-LTSPICE_C0402
EPD_CS: TPTP20R; TP20R
EPD_DC: TPTP20R; TP20R
EPD_RST: TPTP20R; TP20R
GND: TPTP20R; TP20R
IC1: BD5229G-TR; SOT95P280X125-5N
IC4: XC6220A331MR-G; SOT95P280X120-5N
INT_RTC: TPTP20R; TP20R
J1: FH34SRJ-24S-0.5SH_99_; FH34SRJ24S05SH99
J2: SAMACSYS_PARTS_USB4110-GF-A; SAMACSYS_PARTS_USB4110GFA
J3: QWIIC_RIGHT_ANGLE; JST04_1MM_RA
J4: 112A-TAAR-R03_ATTEND; 112ATAARR03ATTEND
L1: 68uH; IND_4828-WE-TPC_WRE
MCP73831: ESP32_WROVER_SPARKFUN-IC-POWER_MCP73831; ESP32_WROVER_SPARKFUN-IC-POWER_SOT23-5
MISO: TPTP20R; TP20R
MOSI: TPTP20R; TP20R
PFMF.050.1: ESP32C6_VARISTORCN1812; ESP32C6_VARISTOR_CT/CN1812
Q1, Q2: 20V/4.2A/52mΩ/1.4W; ESP32_WROVER_SPARKFUN-DISCRETESEMI_SOT23-3
Q3: SI1308EDL-T1-GE3; SOT65P210X110-3N
R1, R1-PINH, R1-PINH1, R2-PINH, R2-PINH1, R5, R6, R7, R8, R9, R10: 10K; ESP32_WROVER_EAGLE-LTSPICE_R0402
R1_BAT: 200; ESP32_WROVER_EAGLE-LTSPICE_R0402
R1_PWRUSB: 100K; ESP32_WROVER_EAGLE-LTSPICE_R0402
R2: 2.2; ESP32_WROVER_EAGLE-LTSPICE_R0402
R2-USB, R2-USB1: 5k1; ESP32_WROVER_EAGLE-LTSPICE_R0402
R2_BAT: 2K; ESP32_WROVER_EAGLE-LTSPICE_R0402
R3: 0.47; ESP32_WROVER_EAGLE-LTSPICE_R0402
R4: 10k; ESP32_WROVER_EAGLE-LTSPICE_R0402
RESET_BUTTON: BUTTON_CUSYOMV1; MYBUTTON
RX: TPTP20R; TP20R
R_BOOT: 10K; ESP32_WROVER_EAGLE-LTSPICE_R0402
R_CAPACITOR: 15; ESP32_WROVER_EAGLE-LTSPICE_R0402
R_CHANGE: 10K; ESP32_WROVER_EAGLE-LTSPICE_R0402
R_CL1: 10K; ESP32_WROVER_EAGLE-LTSPICE_R0402
R_RESET: 10K; ESP32_WROVER_EAGLE-LTSPICE_R0402
SCK: TPTP20R; TP20R
SENSOR2: ESP32_WROVER_BME680_BME680; ESP32_WROVER_BME680_PSON80P300X300X100-8N
SJ1: SJ
TP5: TPTP20R; TP20R
TX: TPTP20R; TP20R
U1: W25Q512JVEIQ; SON127P600X800X80-9N
U2: ESP32-C6-WROOM-1-N8; XCVR_ESP32-C6-WROOM-1-N8
U3: DS3231SN#; SOIC127P1032X265-16N
U4: MAX17048G+T10; SON50P200X200X80-9N
VBAT: TPTP20R; TP20R
VBUS: TPTP20R; TP20R

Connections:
3V3: 3V3.TP, C1_BAT2.1, C3.+, C9.1, D7.2 (ANODE), IC1.2 (VDD), IC4.5 (VOUT), J3.2, J4.P4 (VDD), Q2.3 (D), R1.2, R1-PINH1.2, R2-PINH1.2, R5.2, R6.2, R7.2, R8.2, R9.2, R10.2, R_BOOT.2, R_CHANGE.2, R_CL1.2, R_RESET.2, U1.3 (!WP!(IO2)), U1.7 (!HOLD!/!RESET!(IO3)), U1.8 (VCC), U2.2 (3V3), U3.2 (VCC)
32KHZ: R2-PINH1.1, U2.9 (IO1), U3.1 (32KHZ)
DN: D1.1 (I/O1_1), J2.A7, J2.B7
DP: D1.3 (I/O2_1), J2.A6, J2.B6
EPD_3V3: C7.1, EPD_3V3.TP, EPD_C5.2, J1.15, J1.16, L1.2, Q2.2 (S)
EPD_3V3_C: EPD_3V3_C.TP, Q2.1 (G), R_CL1.1, U2.18 (IO20)
EPD_BUSY: EPD_BUSY.TP, J1.9, U2.26 (IO3)
EPD_CS: D6.2, EPD_CS.TP, J1.12, R9.1, U2.11 (IO10)
EPD_DC: EPD_DC.TP, J1.11, U2.5 (IO5)
EPD_RST: EPD_RST.TP, J1.10, U2.21 (IO23)
FLASH_CS: D9.2, R5.1, U1.1 (!CS), U2.12 (IO11)
GDR: J1.2, Q3.1 (G), R4.2
GND: BOOT_BUTTON.1, BOOT_BUTTON.2, C1.2, C1_BAT.2, C1_BAT1.2, C1_BAT2.2, C2.2, C2_BAT.2, C3.-, C4_USB.2, C5.2, C5_USB.2, C6.2, C7.2, C8.2, C9.2, C10.2, C10_SUPERCAP.1, CHANGE_BUTTON.1, CHANGE_BUTTON.2, C_DELAY.2, D1.5 (VBUS), D3.1 (K), D6.1, D8.1, D9.1, D10.1, D11.1, D12.1, EPD_C1.1, EPD_C2.1, EPD_C5.1, EPD_C6.1, EPD_C7.1, EPD_C8.1, EPD_C9.1, EPD_C10.1, EPD_C11.1, EPD_C12.1, GND.TP, IC1.3 (GND), IC4.2 (VSS), J1.8, J1.17, J1.MP1, J1.MP2, J2.A1, J2.A12, J2.B1, J2.B12, J2.MP1, J2.MP2, J2.MP3, J2.MP4, J3.1, J4.G1 (GND_1), J4.G2 (GND_2), J4.G3 (GND_3), J4.G4 (GND_4), J4.P6 (VSS), MCP73831.2 (VSS), R1_PWRUSB.1, R2.1, R2-USB.2, R2-USB1.1, R2_BAT.1, R4.1, RESET_BUTTON.1, RESET_BUTTON.2, SENSOR2.1 (GND), SENSOR2.5 (SDO), SENSOR2.7 (GND), SJ1.1, TP5.TP, U1.4 (GND), U1.9 (EXP), U2.1 (GND), U2.28 (GND), U2.29_1 (GND), U2.29_2 (GND), U2.29_3 (GND), U2.29_4 (GND), U2.29_5 (GND), U2.29_6 (GND), U2.29_7 (GND), U2.29_8 (GND), U2.29_9 (GND), U3.13 (GND), U4.1 (CTG), U4.4 (GND), U4.6 (QSTRT), U4.9 (EP)
GPIO8: R1.1, U2.10 (IO8)
I2C_PW: C1.1, C2.1, R1-PINH.2, R2-PINH.2, SENSOR2.2 (CSB), SENSOR2.6 (VDDIO), SENSOR2.8 (VDD), U2.17 (IO19)
INT_RTC: INT_RTC.TP, R1-PINH1.1, U2.8 (IO0), U3.3 (SQW/!INT)
IO/BOOT: BOOT_BUTTON.3, BOOT_BUTTON.4, C6.1, R_BOOT.1, U2.15 (IO9)
IO/CHANGE: C10.1, CHANGE_BUTTON.3, CHANGE_BUTTON.4, R_CHANGE.1, U2.23 (IO15)
MISO: D12.2, J4.P7 (DAT0), MISO.TP, R8.1, U1.2 (DO(IO1)), U2.27 (IO2)
MOSI: D11.2, J1.14, J4.P3 (CMD), MOSI.TP, R7.1, U1.5 (DI(IO0)), U2.7 (IO7)
unnamed: J2.A5, R2-USB1.2
unnamed: J2.B5, R2-USB.1
unnamed: C1_BAT1.1, D2.1 (CATHODE), IC4.1 (VIN), IC4.3 (CE), Q1.2 (S)
unnamed: MCP73831.5 (PROG), R2_BAT.2
unnamed: EPD_C2.2, J1.5
unnamed: EPD_C1.2, J1.4
unnamed: CHG_LED.C, R1_BAT.1
unnamed: MCP73831.1 (STAT), R1_BAT.2
unnamed: EPD_C12.2, J1.24
unnamed: C_DELAY.1, IC1.5 (CT)
unnamed: EPD_C10.2, J1.22
unnamed: C4.1, D3.2 (A), D4.1 (K)
unnamed: EPD_C8.2, J1.20
unnamed: EPD_C7.2, J1.19
unnamed: EPD_C6.2, J1.18
unnamed: D7.1 (CATHODE), R_CAPACITOR.1
PREVGH: D5.1 (K), EPD_C9.2, J1.21
PREVGL: D4.2 (A), EPD_C11.2, J1.23
RESE: J1.3, Q3.2 (S), R3.2
RESE': R2.2, R3.1, SJ1.2
RESET: C5.1, IC1.1 (VOUT), RESET_BUTTON.3, RESET_BUTTON.4, R_RESET.1, U2.3 (EN)
RTC_RST: U2.16 (IO18), U3.4 (!RST)
RX: RX.TP, U2.24 (RXD0/GPIO17)
SCK: D10.2, J1.13, J4.P5 (CLK), R6.1, SCK.TP, U1.6 (CLK), U2.6 (IO6)
SCL: J3.4, R2-PINH.1, SENSOR2.4 (SCK), U2.20 (IO22), U3.16 (SCL), U4.7 (SCL)
SDA: J3.3, R1-PINH.1, SENSOR2.3 (SDI), U2.19 (IO21), U3.15 (SDA), U4.8 (SDA)
SRC: C4.2, D5.2 (A), L1.1, Q3.3 (D)
SS_SD: D8.2, J4.P2 (CD/DAT3), R10.1, U2.4 (IO4)
TX: TX.TP, U2.25 (TXD0/GPIO16)
USB_D+: D1.4 (I/O2_2), U2.14 (IO13)
USB_D-: D1.6 (I/O1_2), U2.13 (IO12)
VBAT: C2_BAT.1, MCP73831.3 (VBAT), Q1.3 (D), U4.2 (CELL), U4.3 (VDD), VBAT.TP
VBUS: C1_BAT.1, C4_USB.1, C5_USB.1, CHG_LED.A, D1.2 (GND), D2.2 (ANODE), MCP73831.4 (VIN), PFMF.050.1.2, Q1.1 (G), R1_PWRUSB.2, VBUS.TP
VRTC: C8.1, C10_SUPERCAP.2, R_CAPACITOR.2, U3.14 (VBAT)
VUSB: J2.A4, J2.A9, J2.B4, J2.B9, PFMF.050.1.1

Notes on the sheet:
USB C connector & ESD protection
LDO Voltage Regulator
SD Card
Display Type Selector
E-Paper Drive Circuit
Li-Po Battery Charging Controller
ESP32 C6
E-Paper Display Header
EPD Power
Environmental Sensor BME688
Voltage Supervisor + Reset & Boot / IO Button
Battery Charge Level
RTC Module DS3231SN
Test Pads
Qwiic / Stemma QT
SPI ESD Protection Lines
External NOR Flash 64MB

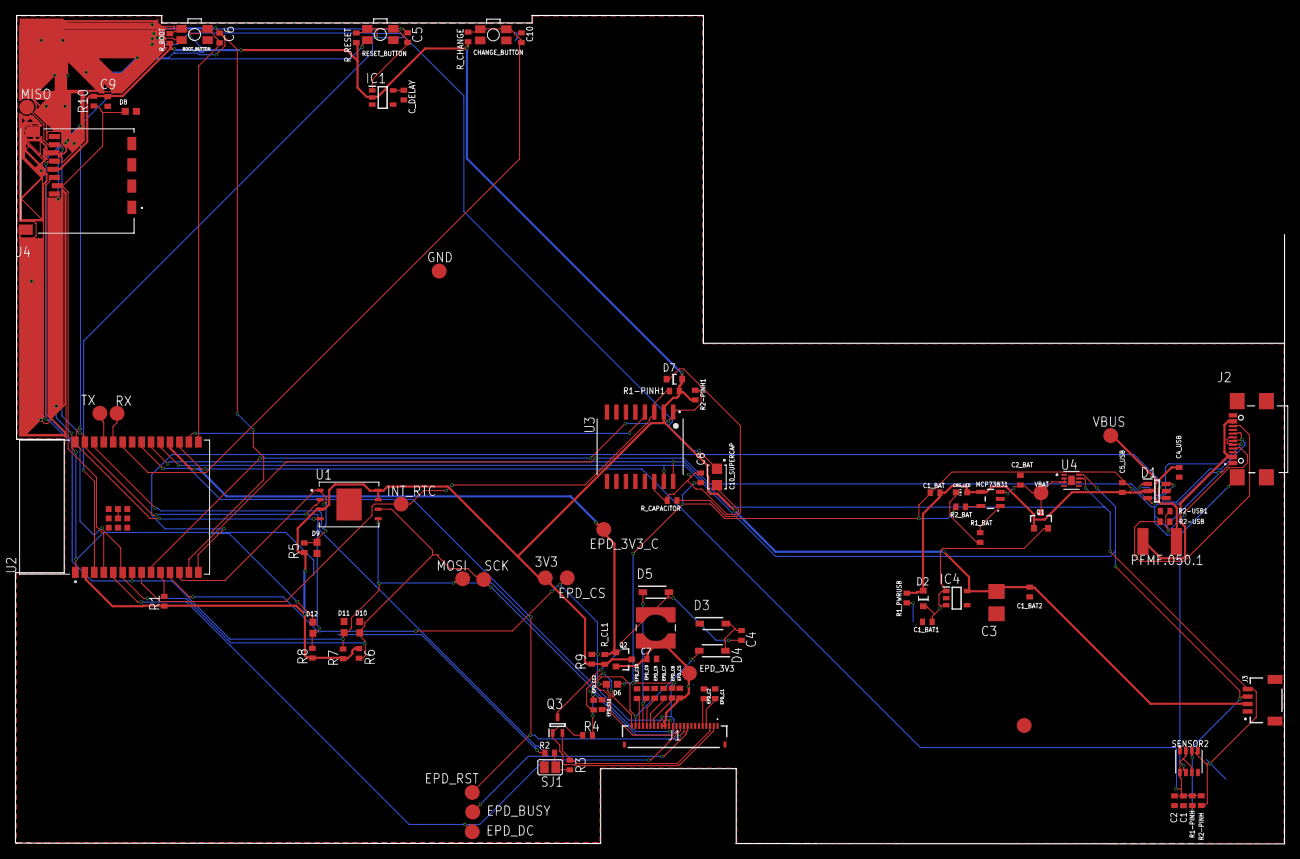
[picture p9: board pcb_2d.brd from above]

Board: 2 copper layers, 170.3 x 111.2 mm, 103 parts (0 on the bottom side), 55 nets.

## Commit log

2025-04-06 Final commit
    [bill of materials.csv, board.brd, pick and place.csv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]
2025-04-15 am reparat chestii
    [pcb_2d.brd, schematic.sch]

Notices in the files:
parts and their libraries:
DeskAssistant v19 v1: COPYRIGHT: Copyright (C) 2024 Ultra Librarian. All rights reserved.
